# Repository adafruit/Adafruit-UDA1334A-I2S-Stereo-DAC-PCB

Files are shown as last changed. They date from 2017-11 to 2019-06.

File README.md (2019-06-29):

## Adafruit UDA1334A I2S Stereo DAC PCB

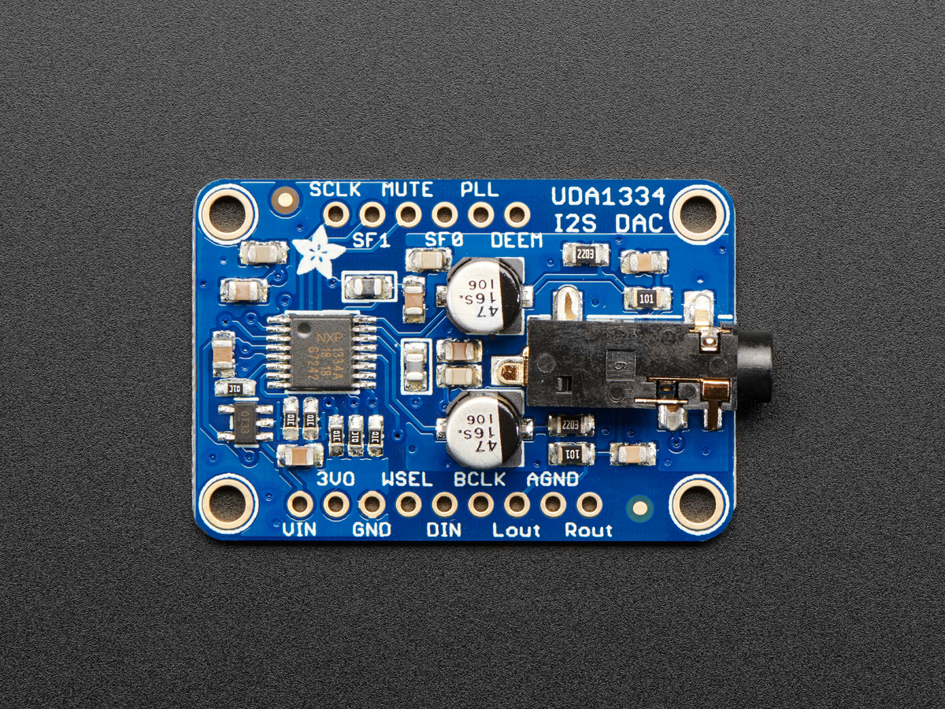
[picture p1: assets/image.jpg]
<a href="http://www.adafruit.com/products/3678"><br/>
Click here to purchase one from the Adafruit shop</a>

PCB files for the Adafruit UDA1334A I2S Stereo DAC Breakout. Format is EagleCAD schematic and board layout

For more details, check out the product page at
* https://www.adafruit.com/products/3678

### Description

This fully-featured UDA1334A I2S Stereo DAC breakout is a perfect match for any I2S-output audio interface. It's affordable but sounds great! The NXP UDA1334A is a jack-of-all-I2S-trades: you can use 3.3V - 5V logic levels (a rarity), and can process multiple different formats by setting two pins to high or low. The DAC will process data immediately, and give you a clear, analog, stereo line level output. It's even cool with MCLK-less I2S interfaces such as the Raspberry Pi (which it's ideal for) - a built in PLL will generate the proper clock from the bitclock signal.

For inputs, you can use classic I2S (the default) or 16-bit, 20-bit or 24-bit left justified data. You can set it up to take an input system/master clock but we default-set it to just generate it for you, so you only need to connect Data In, Word Select (Left/Right Clock) and Bit Clock lines. If you want, there's a mute pin and a de-emphasis filter you can turn on.

We put in plenty of ferrite beads, a low-dropout regulator, and the recommended band-pass filter so you get a very nice clean output. With a sine-wave generator we swept through 20-20KHz and saw no attenuation or distortion. Plug into either the 3.5mm stereo headphone jack or the breadboard-friendly pads. We think you'll be pleased with this DAC!

Each order comes with one I2S Stereo DAC breakout and some header you can solder on. 

### License

Adafruit invests time and resources providing this open source design, please support Adafruit and open-source hardware by purchasing products from [Adafruit](https://www.adafruit.com)!

Designed by Limor Fried/Ladyada for Adafruit Industries.

Creative Commons Attribution/Share-Alike, all text above must be included in any redistribution. See license.txt for additional details.

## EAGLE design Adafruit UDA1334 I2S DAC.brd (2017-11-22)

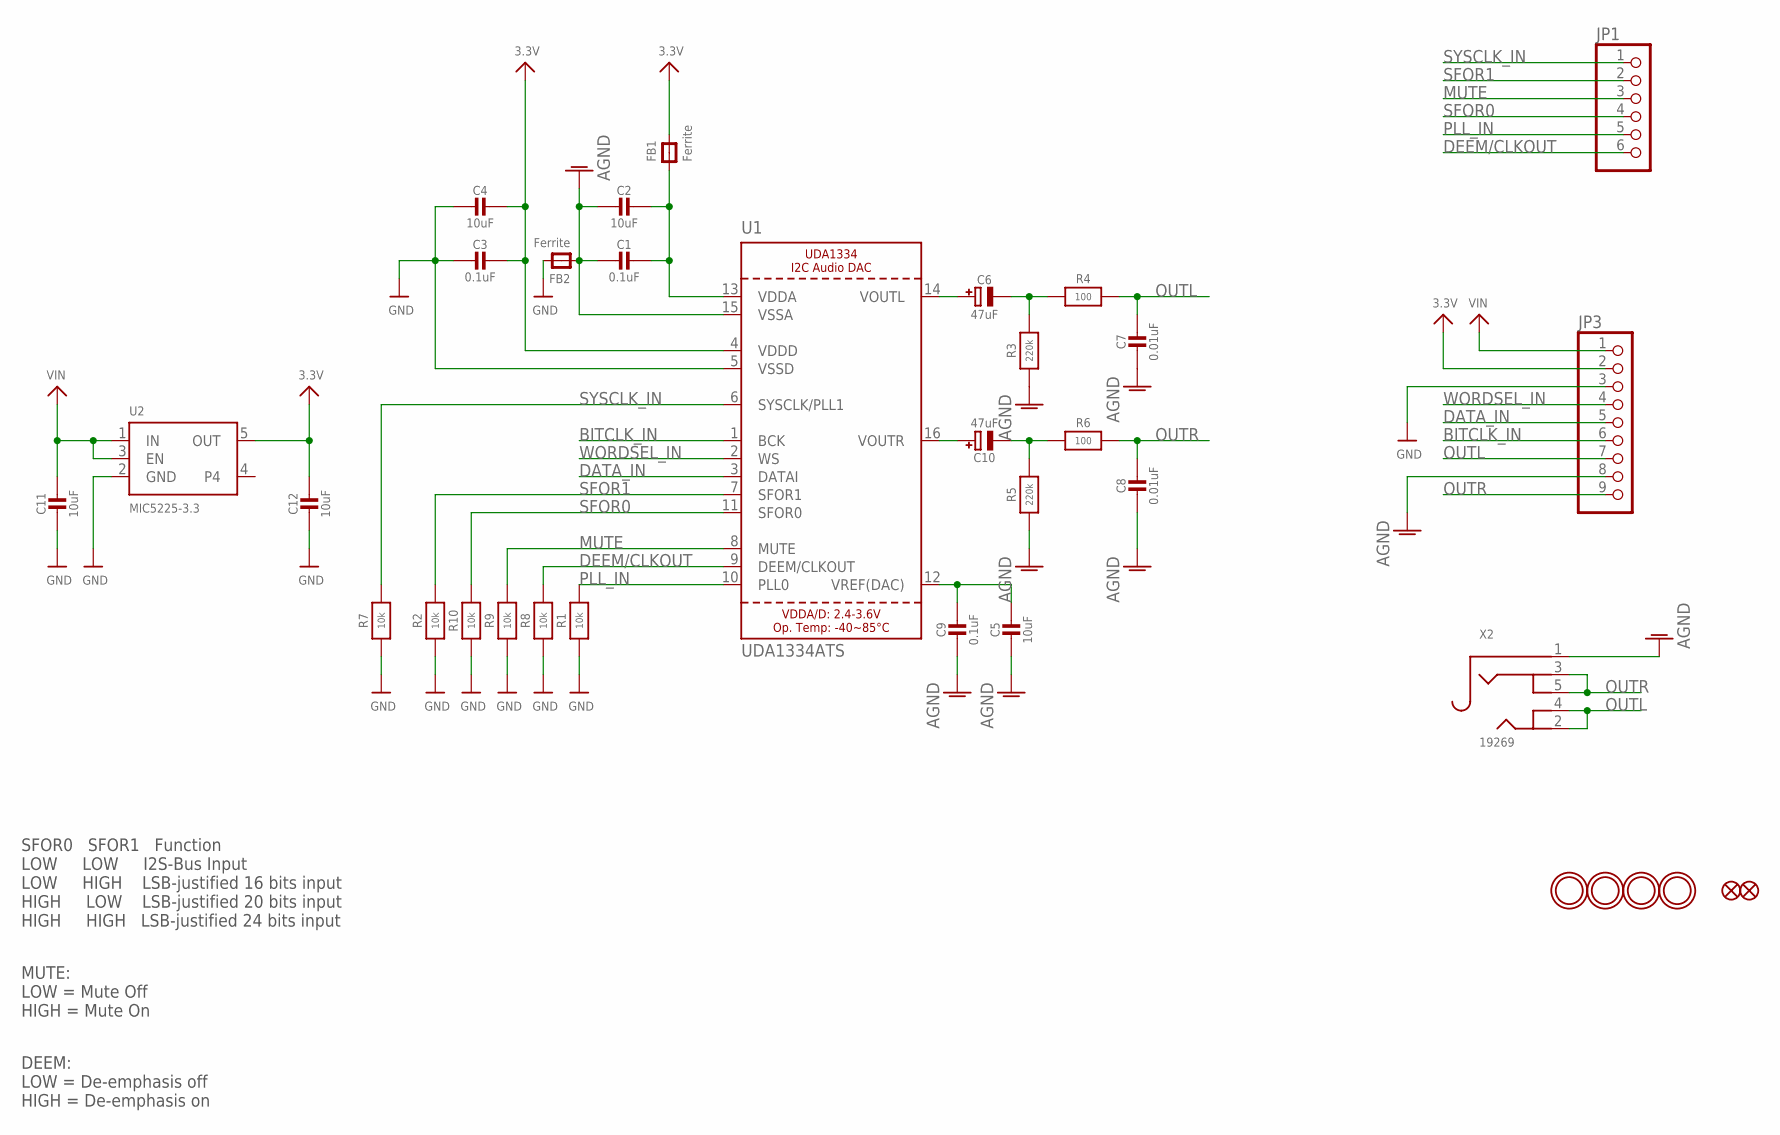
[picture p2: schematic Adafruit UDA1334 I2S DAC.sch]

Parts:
C1, C3, C9: 0.1uF; 0805-NO
C2, C4, C5, C11, C12: 10uF; 0805-NO
C6, C10: 47uF; PANASONIC_C
C7, C8: 0.01uF; 0805-NO
FB1, FB2: Ferrite; 0805
FID1, FID2: FIDUCIAL_1MM
JP1: HEADER-1X670MIL; 1X06_ROUND_70
JP3: HEADER-1X970MIL; 1X09_ROUND_70
R1, R2, R7, R8, R9, R10: 10k; 0603-NO
R3, R5: 220k; 0805-NO
R4, R6: 100; 0805-NO
U1: UDA1334ATS; SSOP16_4.4MM
U2: MIC5225-3.3; SOT23-5
U$11, U$12, U$13, U$14: MOUNTINGHOLE2.5; MOUNTINGHOLE_2.5_PLATED
X2: 19269; 4UCONN_19269

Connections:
3.3V: C3.1, C4.1, C12.1, FB1.2, JP3.2, U1.4 (VDDD), U2.5 (OUT)
AGND: C1.2, C2.2, C5.2, C7.2, C8.2, C9.2, FB2.1, JP3.8, R3.1, R5.1, U1.15 (VSSA), X2.1
BITCLK_IN: JP3.6, U1.1 (BCK)
DATA_IN: JP3.5, U1.3 (DATAI)
DEEM/CLKOUT: JP1.6, R8.2, U1.9 (DEEM/CLKOUT)
GND: C3.2, C4.2, C11.2, C12.2, FB2.2, JP3.3, R1.1, R2.1, R7.1, R8.1, R9.1, R10.1, U1.5 (VSSD), U2.2 (GND)
MUTE: JP1.3, R9.2, U1.8 (MUTE)
unnamed: C5.1, C9.1, U1.12 (VREF(DAC))
unnamed: C1.1, C2.1, FB1.1, U1.13 (VDDA)
unnamed: C10.+, U1.16 (VOUTR)
unnamed: C6.+, U1.14 (VOUTL)
unnamed: C6.-, R3.2, R4.1
unnamed: C10.-, R5.2, R6.1
OUTL: C7.1, JP3.7, R4.2, X2.2, X2.4
OUTR: C8.1, JP3.9, R6.2, X2.3, X2.5
PLL_IN: JP1.5, R1.2, U1.10 (PLL0)
SFOR0: JP1.4, R10.2, U1.11 (SFOR0)
SFOR1: JP1.2, R2.2, U1.7 (SFOR1)
SYSCLK_IN: JP1.1, R7.2, U1.6 (SYSCLK/PLL1)
VIN: C11.1, JP3.1, U2.1 (IN), U2.3 (EN)
WORDSEL_IN: JP3.4, U1.2 (WS)

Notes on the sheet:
MUTE: LOW = Mute Off HIGH = Mute On
DEEM: LOW = De-emphasis off HIGH = De-emphasis on
SFOR0 SFOR1 Function LOW LOW I2S-Bus Input LOW HIGH LSB-justified 16 bits input HIGH LOW LSB-justified 20 bits input HIGH HIGH LSB-justified 24 bits input

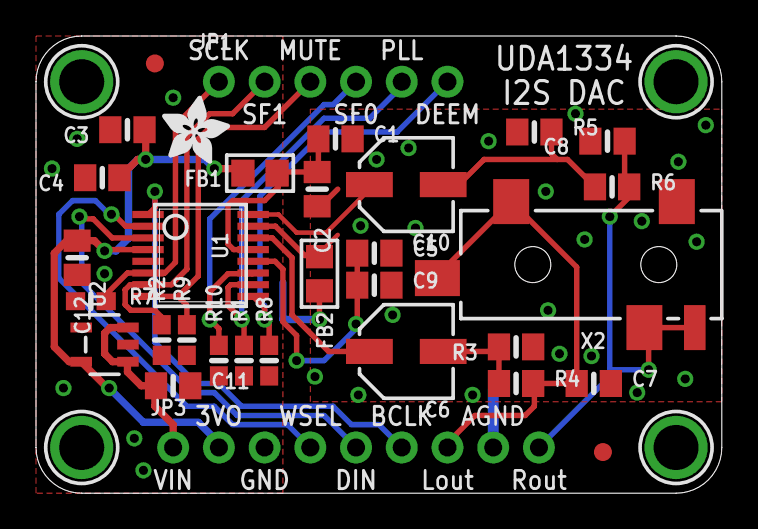
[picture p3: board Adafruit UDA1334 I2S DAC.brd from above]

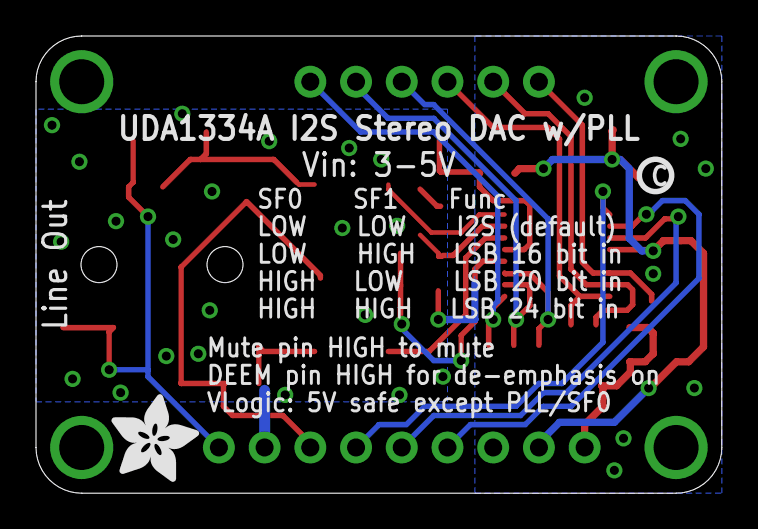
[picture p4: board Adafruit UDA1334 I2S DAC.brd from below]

Board: 2 copper layers, 38.1 x 25.4 mm, 38 parts (2 on the bottom side), 21 nets.

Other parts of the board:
U$5: PCBFEAT-REV-040
U$6: ADAFRUIT_5MM
U$29: ADAFRUIT_3.5MM

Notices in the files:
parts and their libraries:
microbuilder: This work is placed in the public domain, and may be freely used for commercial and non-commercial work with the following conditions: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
